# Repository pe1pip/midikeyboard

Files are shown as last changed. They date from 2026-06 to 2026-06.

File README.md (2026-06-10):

# Midi Keyboard

[[_TOC_]]

## Introduction

Copyright 2026 Remco Post

[License AGPL](./LICENSE.md)

## de-mux

The software is designed to use a one-of-eight demux like the 74hc238 to scan a keyboard. With 8 lines this could
be up to 5 octave (and a bit).

## Stops

The stops are not multiplexed. The software supports 8 stops. The trick is that each of the stops cycles through
6 options:

- off
- on (no shift)
- on (1 up)
- on (1 down)
- on (2 up)
- on (2 down)

On a stop change the software first sends 'key off', unless the stop is currently off, followed by the key on that
corresponds with the stop and shift. To facilitate that, each stop actually uses 5 values: 2, 3, 4, 5 and 6 with
an offset in mutiples of 8 for each stop.

### Stop state

The stop state is stored in an array with a value that corresponds to one of the 6 possible options. The state of the
stop buttons is also stored. On a LOW to HIGH transition the stop state is updated and the new value is transmitted.

## MIDI channels

Configurable in code, but defined as:

0: stops
1: keys

## Key state

The (previous) key state is stored in an array. If the value has changed the new value is send over the serial line immediately.

## Keyboard

The keyboard is a simple matrix, 8 input lines, diodes to each key contact and then 8 lines. The current flows from 'Keys in group' to 'Group'.
The (previous) key state is stored in an array. If the value has changed the new value is send over the serial line
immediately.

### Groups

| keys | pin | giga pin |
|---|-----|---|
| 1-8  | 16  | 53 |
| 9-16 | 1 | 52 |
| 17-24| 15  | 51 |
| 25-32| 2 | 50 |
| 33-40| 14  | 49 |
| 41-48| 3 | 48 |
| 49-56| 13  | 47 |
| 57-61| 4 | 46 |

### Keys in group

| key | pin | giga pin |
|-----|-----|---|
| 1 | 10  | 41 |
| 2 | 5 | 44 |
| 3 | 6 | 42 |
| 4 | 12  | 45 |
| 5 | 11  | 43 |
| 6 | 9 | 39 |
| 7 | 8 | 38 |
| 8 | 7 | 40 |

### Scanning the keyboard

The 'group' lines are pulled up via the internal pullup resister. If a key is depressed and the 'Keys in group'
line is `LOW`, then the 'group' line goes `LOW`. So, normally all 'Key in group' lines are high. Then one by one
each is set to `LOW`, and all 'Group' lines are read to see which of the keys are depressed; those will read `LOW`.
After a key has changed, we don't read the new state for some time `DEBOUNCE` to debounce the keypresses and releases.

## Calcant

Calcant is a special switch, it basically turns off the blower. To draw attention to the blower being off,
the LED will blink. This switch is debounced in the same manner as as the keyboard.

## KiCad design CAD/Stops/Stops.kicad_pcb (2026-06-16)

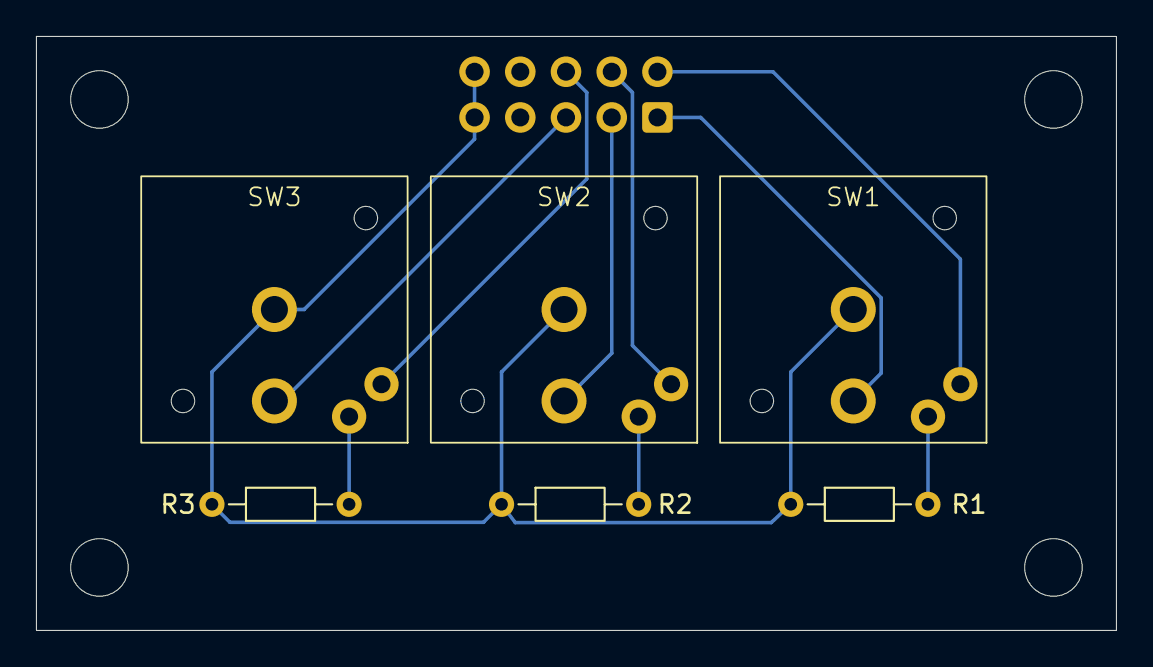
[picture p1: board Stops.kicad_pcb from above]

Board: 2 copper layers, 60.0 x 33.0 mm, 11 parts (1 on the bottom side), 10 nets.

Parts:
H1, H2, H3, H4: MountingHole; MountingHole_3.2mm_M3
J1: Conn_01x08_Socket; IDC-Header_2x05_P2.54mm_Latch_Horizontal
R1, R2, R3: 270; R_Axial_DIN0204_L3.6mm_D1.6mm_P7.62mm_Horizontal
SW1, SW2, SW3: SW_Push_LED; Marquardt_6425.4111

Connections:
/L1: J1.2, SW1.4 (A)
/L2: J1.4, SW2.4 (A)
/L3: J1.6, SW3.4 (A)
/SW1: J1.1, SW1.2
/SW2: J1.3, SW2.2
/SW3: J1.5, SW3.2
GND: J1.9, J1.10, R1.1, R2.1, R3.1, SW1.1, SW2.1, SW3.1
unnamed: R1.2, SW1.3 (K)
unnamed: R2.2, SW2.3 (K)
unnamed: R3.2, SW3.3 (K)

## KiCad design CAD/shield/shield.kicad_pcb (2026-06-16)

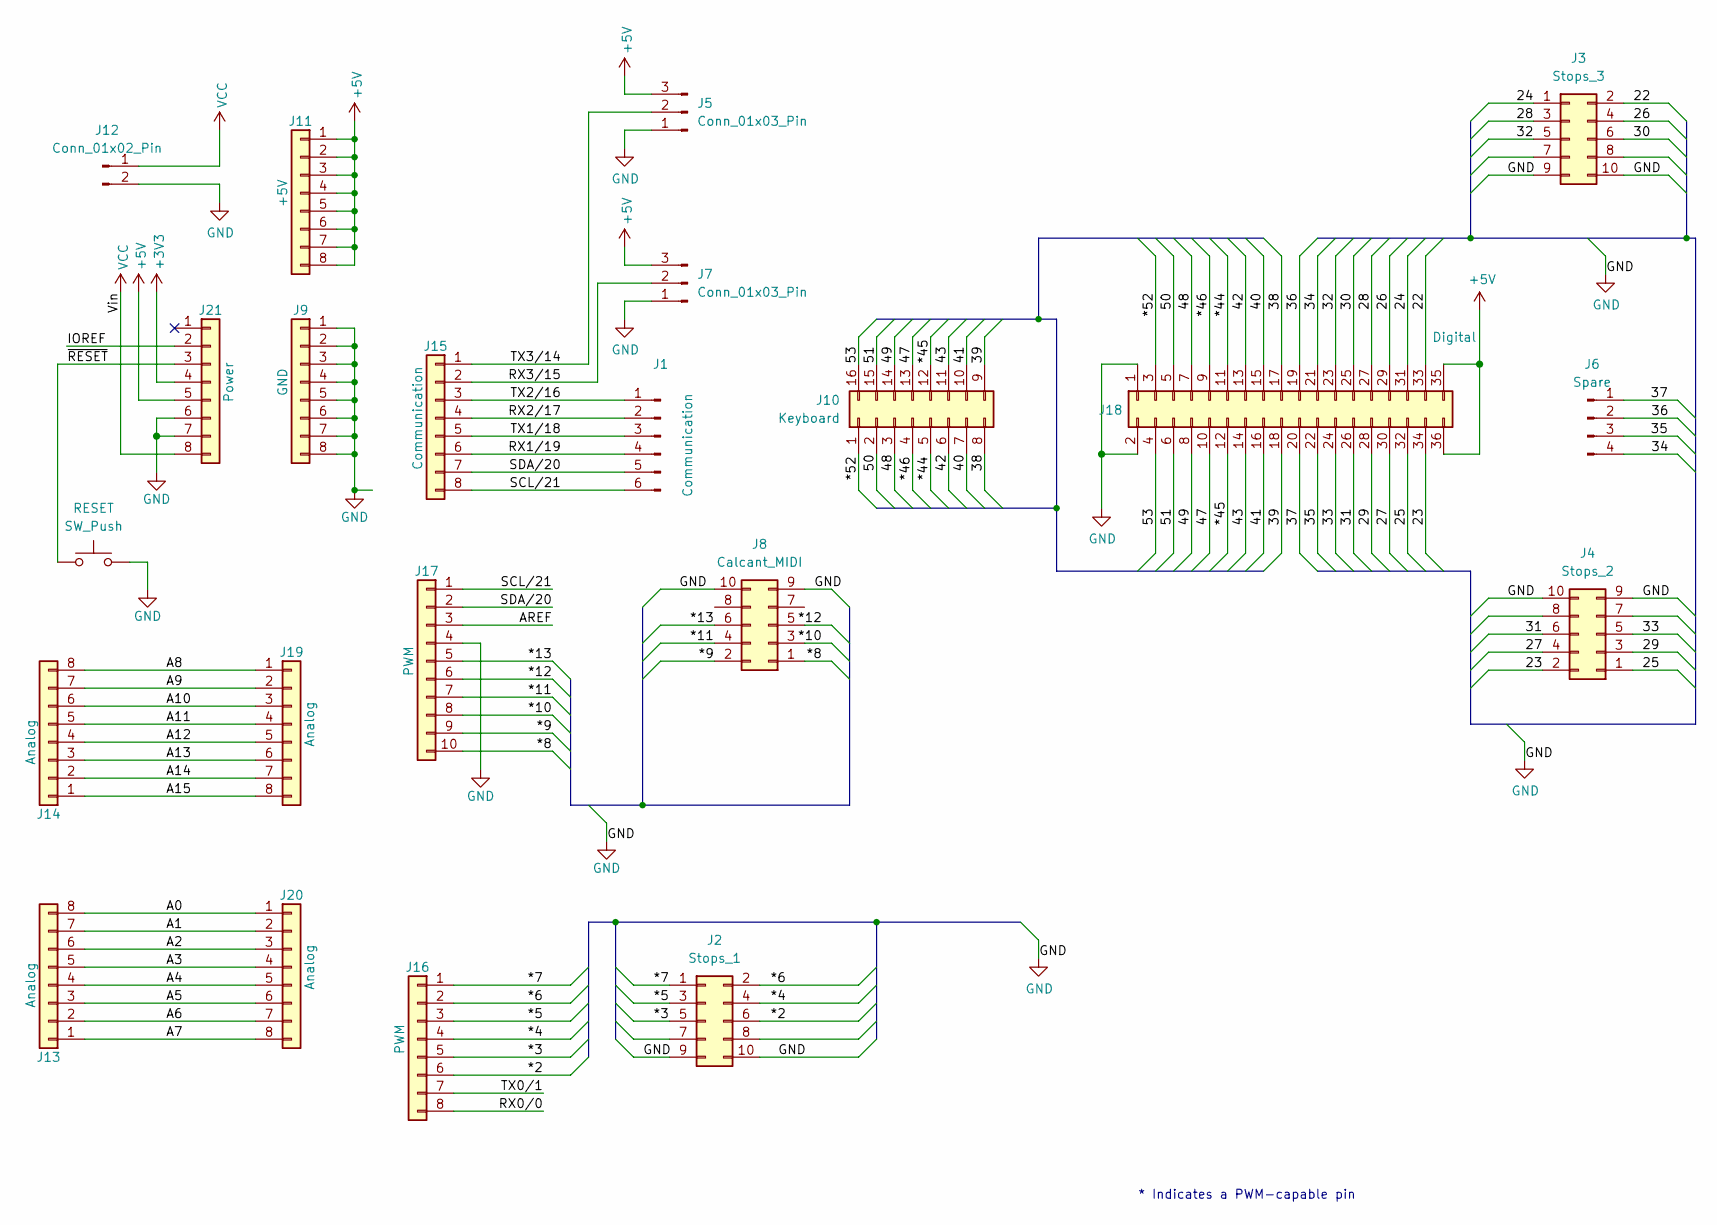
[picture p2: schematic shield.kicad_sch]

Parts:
J1: Communication; PinHeader_1x06_P2.54mm_Vertical
J2: Stops_1; IDC-Header_2x05_P2.54mm_Latch_Vertical
J3: Stops_3; IDC-Header_2x05_P2.54mm_Latch_Vertical
J4: Stops_2; IDC-Header_2x05_P2.54mm_Latch_Vertical
J5, J7: Conn_01x03_Pin; PinHeader_1x03_P2.54mm_Vertical
J6: Spare; PinHeader_1x04_P2.54mm_Vertical
J8: Calcant_MIDI; IDC-Header_2x05_P2.54mm_Latch_Vertical
J9: GND; PinHeader_1x08_P2.54mm_Vertical
J10: Keyboard; DIP-16_W7.62mm_Socket
J11: +5V; PinHeader_1x08_P2.54mm_Vertical
J12: Conn_01x02_Pin; PinHeader_1x02_P2.54mm_Vertical
J13, J14, J19, J20: Analog; PinHeader_1x08_P2.54mm_Vertical
J15: Communication; PinHeader_1x08_P2.54mm_Vertical
J16: PWM; PinHeader_1x08_P2.54mm_Vertical
J17: PWM; PinHeader_1x10_P2.54mm_Vertical
J18: Digital; PinHeader_2x18_P2.54mm_Vertical
J21: Power; PinHeader_1x08_P2.54mm_Vertical
RESET: SW_Push; SW_Push_1P1T_NO_CK_KMR2

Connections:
+3V3: J21.4
+5V: J5.3, J7.3, J11.1, J11.2, J11.3, J11.4, J11.5, J11.6, J11.7, J11.8, J18.35, J18.36, J21.5
/22: J3.2, J18.33
/23: J4.2, J18.34
/24: J3.1, J18.31
/25: J4.1, J18.32
/26: J3.4, J18.29
/27: J4.4, J18.30
/28: J3.3, J18.27
/29: J4.3, J18.28
/30: J3.6, J18.25
/31: J4.6, J18.26
/32: J3.5, J18.23
/33: J4.5, J18.24
/34: J6.4, J18.21
/35: J6.3, J18.22
/36: J6.2, J18.19
/37: J6.1, J18.20
/38: J10.8, J18.17
/39: J10.9, J18.18
/40: J10.7, J18.15
/41: J10.10, J18.16
/42: J10.6, J18.13
/43: J10.11, J18.14
/47: J10.13, J18.10
/48: J10.3, J18.7
/49: J10.14, J18.8
/50: J10.2, J18.5
/51: J10.15, J18.6
/53: J10.16, J18.4
/*2: J2.6, J16.6
/*3: J2.5, J16.5
/*4: J2.4, J16.4
/*5: J2.3, J16.3
/*6: J2.2, J16.2
/*7: J2.1, J16.1
/*8: J8.1, J17.10
/*9: J8.2, J17.9
/*10: J8.3, J17.8
/*11: J8.4, J17.7
/*12: J8.5, J17.6
/*13: J8.6, J17.5
/*44: J10.5, J18.11
/*45: J10.12, J18.12
/*46: J10.4, J18.9
/*52: J10.1, J18.3
/A0: J13.8, J20.1
/A1: J13.7, J20.2
/A2: J13.6, J20.3
/A3: J13.5, J20.4
/A4: J13.4, J20.5
/A5: J13.3, J20.6
/A6: J13.2, J20.7
/A7: J13.1, J20.8
/A8: J14.8, J19.1
/A9: J14.7, J19.2
/A10: J14.6, J19.3
/A11: J14.5, J19.4
/A12: J14.4, J19.5
/A13: J14.3, J19.6
/A14: J14.2, J19.7
/A15: J14.1, J19.8
/AREF: J17.3
/IOREF: J21.2
/RX0/0: J16.8
/RX1/19: J1.4, J15.6
/RX2/17: J1.2, J15.4
/RX3/15: J7.2, J15.2
/SCL/21: J1.6, J15.8, J17.1
/SDA/20: J1.5, J15.7, J17.2
/TX0/1: J16.7
/TX1/18: J1.3, J15.5
/TX2/16: J1.1, J15.3
/TX3/14: J5.2, J15.1
/~RESET: J21.3, RESET.1
GND: J2.9, J2.10, J3.9, J3.10, J4.9, J4.10, J5.1, J7.1, J8.9, J8.10, J9.1, J9.2, J9.3, J9.4, J9.5, J9.6, J9.7, J9.8, J12.2, J17.4, J18.1, J18.2, J21.6, J21.7, RESET.2
VCC: J12.1, J21.8

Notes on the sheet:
* Indicates a PWM-capable pin

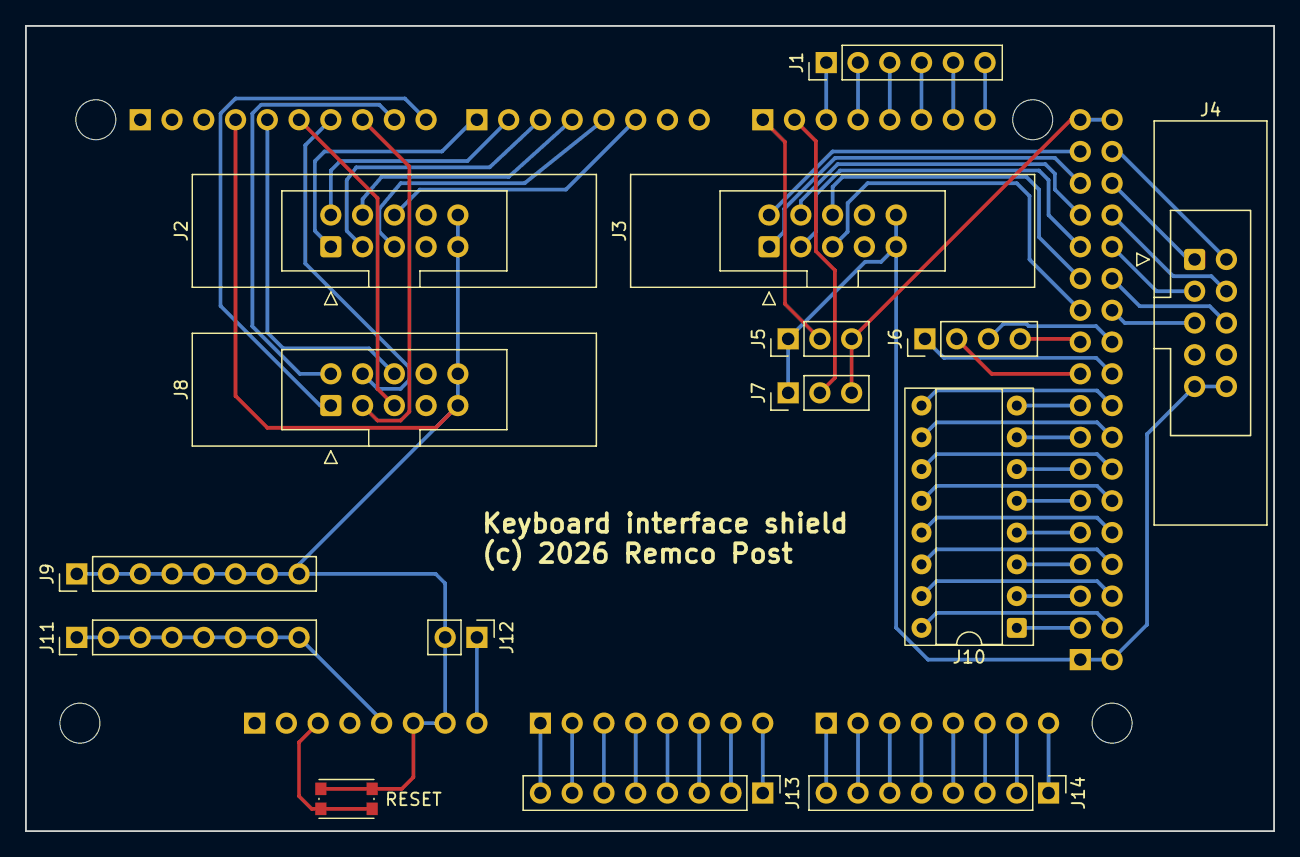
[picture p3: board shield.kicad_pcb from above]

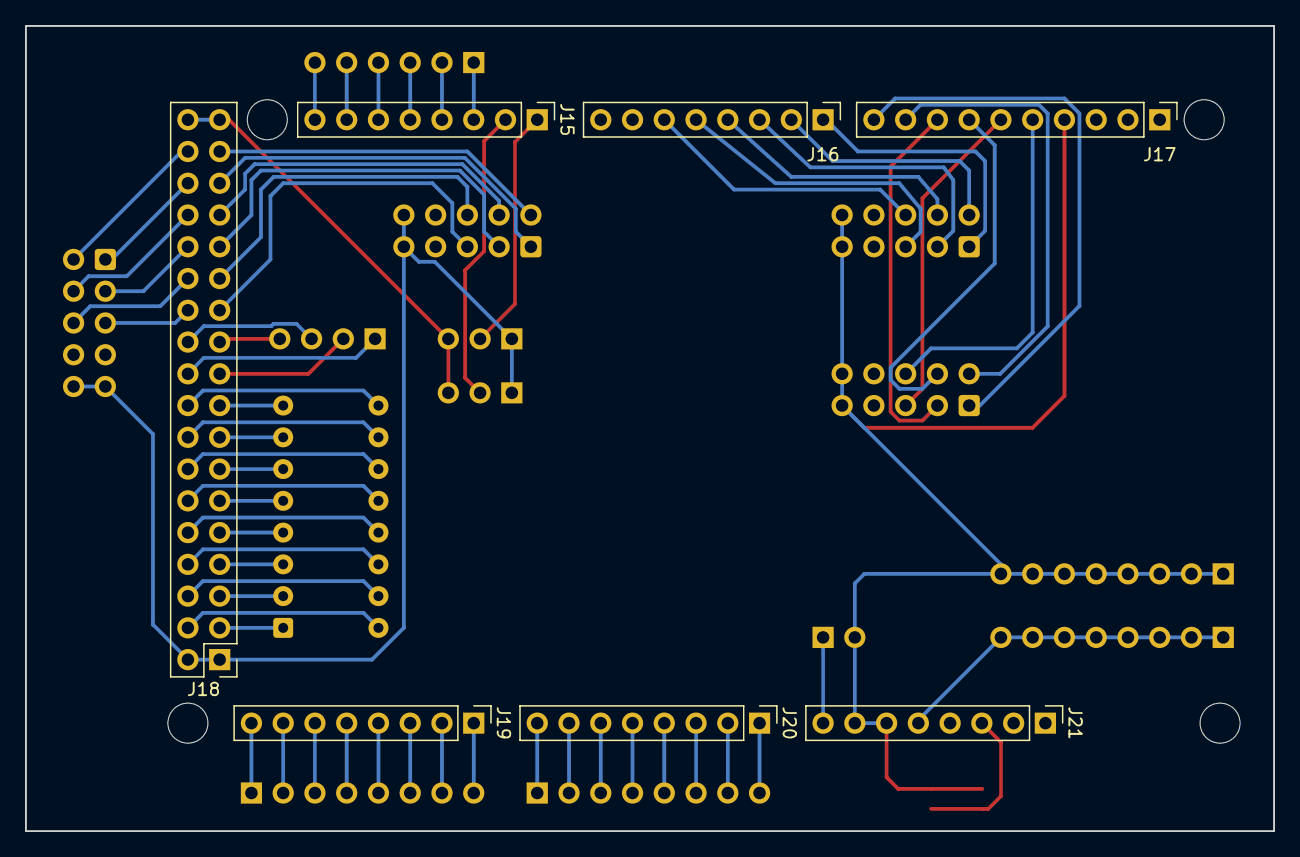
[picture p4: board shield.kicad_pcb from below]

Board: 2 copper layers, 99.8 x 64.4 mm, 26 parts (7 on the bottom side), 72 nets.

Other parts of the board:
MH1, MH2, MH3, MH4: MountingHole_3.2mm

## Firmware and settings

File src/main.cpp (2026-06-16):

/*
Copyright (c) 2026 Remco Post

This program is free software: you can redistribute it and/or modify it under the terms of the
GNU Affero General Public License as published by the Free Software Foundation, either version
3 of the License, or (at your option) any later version.

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
You should have received a copy of the GNU Affero General Public License along with this program.
If not, see <https://www.gnu.org/licenses/>
*/
#include <Arduino.h>
#include <generic.h>
#include <midi.h>
#include <wifiMidi.h>
#include <keyboard.h>
#include <stops.h>
#include <calcant.h> 

void setup() {
  keyboard::init();
  stops::init();
  calcant::init();
#ifdef DEBUG
  Serial.begin(115200);
  while(!Serial); // wait for serial to be ready
  delay(250); // wait for the serial monitor to open
  Serial.println("Keyboard initialized");
  Serial.println("Debug mode enabled");
  stops::initDemo();
#endif
}

void loop() {
  keyboard::scan();
  stops::scan();
  calcant::scan();
  wifiMidi::scan();
  calcant::blinkLed();
  wifiMidi::blinkLed();
}

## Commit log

2026-05-18 fix pin assignment
2026-06-01 Added PCB
    [shield.kicad_pcb, shield.kicad_sch]
2026-06-01 updated schematic
    [shield.kicad_pcb, shield.kicad_sch]
2026-06-02 Adjusted for arduino Due board
2026-06-03 Stop switch PCB
    [Stops.kicad_pcb, Stops.kicad_sch]
2026-06-07 improved footprint
    [Stops.kicad_pcb]
2026-06-09 moved from stop ISR to polling, Mega has too few interrupts
2026-06-13 redo CAD
    [Stops.kicad_pcb, Stops.kicad_sch, shield.kicad_pcb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]
2026-06-13 improved button/led handling
